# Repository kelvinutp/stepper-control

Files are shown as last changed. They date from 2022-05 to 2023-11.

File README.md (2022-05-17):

# stepper controls

This repository will contain the file for controlling stepper motors using a Raspberry pi GPIO and TB6560 drivers

|program|function|
|---|---|
|[clk_signal.py](https://github.com/kelvinutp/stepper-control/blob/main/clock_signal.py)|Generates a constant frequency clock signal (square wave)|
|[only_motors_control.py](https://github.com/kelvinutp/stepper-control/blob/main/only_motors_control.py)|Allows for controlling individual Enable (start/stop) and Direction (changes direction) pin on driver|
|[auto_moving.py](https://github.com/kelvinutp/stepper-control/blob/main/auto_moving.py)|Makes a motor moves repeteadly in prestablished timed sequences|
|[variador.py](https://github.com/kelvinutp/stepper-control/blob/main/variaddor.py)|enables the stepmotor for a soft start and a soft stop by gradually increasing and decreaseing th efrequency|
|[class.py](https://github.com/kelvinutp/stepper-control/blob/main/class.py)|A programmed class that provides all the functionalities for controlling a stepmotor|
|[Django files](https://github.com/kelvinutp/stepper-control/tree/main/django%20files)|a Django project created for providing a sort of UI capable of doing almost everything that is done by code|

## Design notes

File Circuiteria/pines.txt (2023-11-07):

signal=raspberry pin 
clk 18
D1 8
E1 10
D2 16
E3 18
D3 22
E3 24
D4 26
E4 32
D5 36
E5 38
-----
LIMIT SWITCH
L1 31
L2 33
L3 35
L4 37
L5 40

---
ENCODERS
ENC1A 3
ENC1B 5
ENC2A 7
ENC2B 11
ENC3A 13
ENC3B 15
ENC4A 19
ENC4B 21
ENC5A 23
ENC5B 29

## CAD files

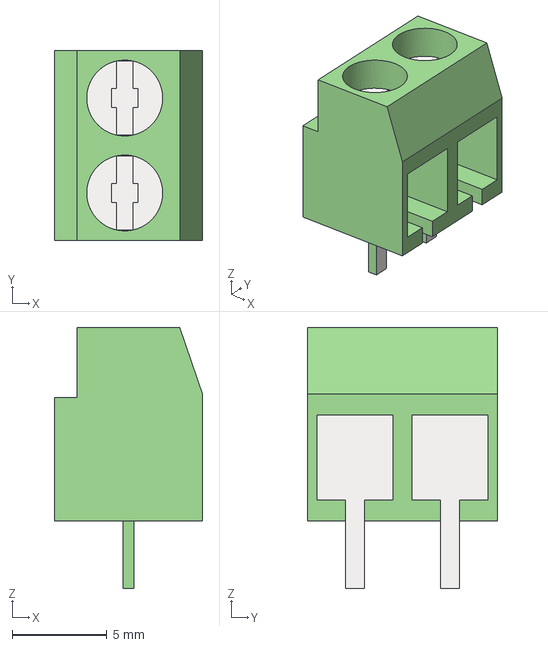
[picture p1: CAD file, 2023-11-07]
Circuiteria/modelos 3d de piezas/bornera 2.step
7.80 x 10.0 x 13.8 mm

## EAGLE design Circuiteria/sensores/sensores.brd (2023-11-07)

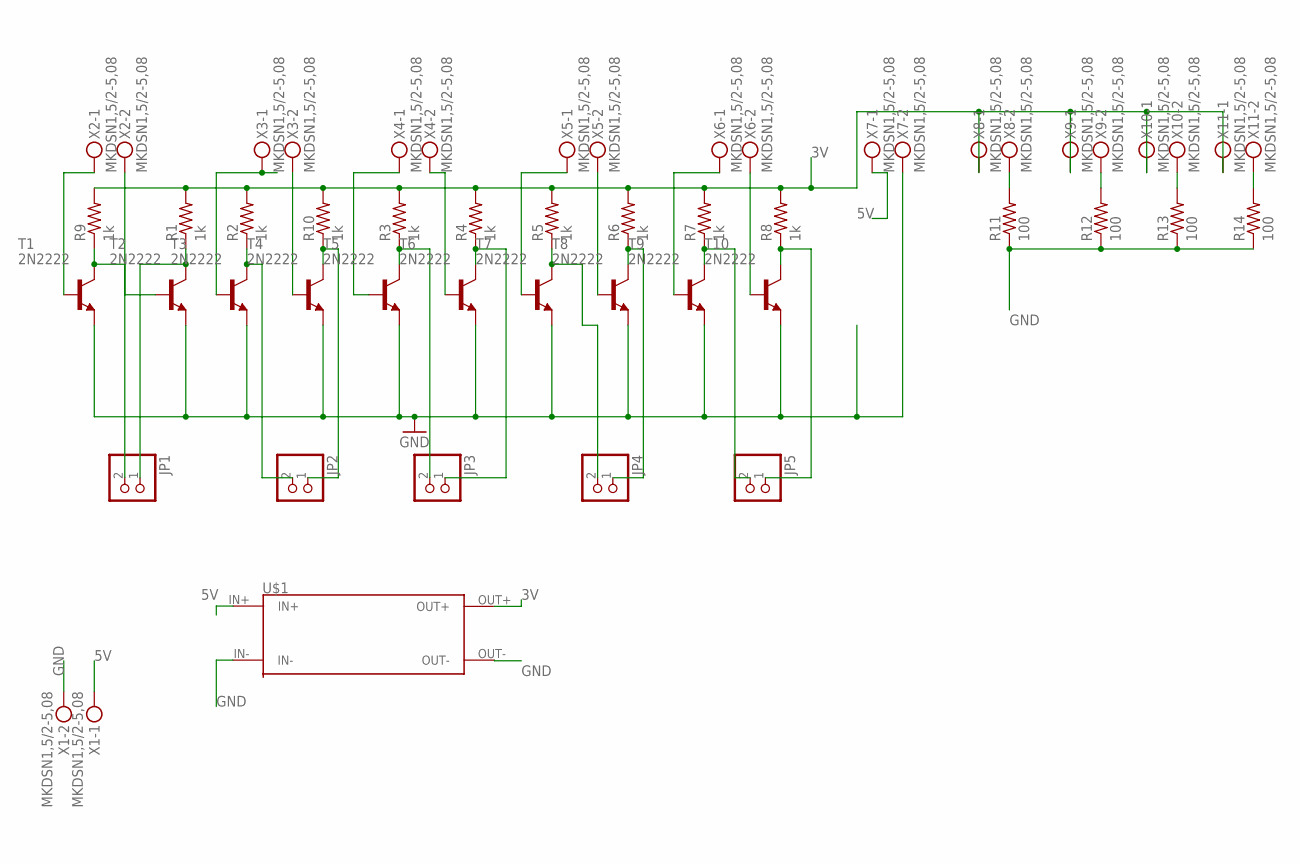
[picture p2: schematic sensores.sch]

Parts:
JP1, JP2, JP3, JP4, JP5: PINHD-1X2; 1X02
R1, R2, R3, R4, R5, R6, R7, R8, R9, R10: 1k; 0207/10
R11, R12, R13, R14: 100; 0207/10
T1, T2, T3, T4, T5, T6, T7, T8, T9, T10: 2N2222
U$1: LM2596
X1, X2, X3, X4, X5, X6, X7, X8, X9, X10, X11: MKDSN1,5/2-5,08

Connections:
3V: R1.2, R2.2, R3.2, R4.2, R5.2, R6.2, R7.2, R8.2, R9.2, R10.2, U$1.OUT+, X8.1, X9.1, X10.1, X11.1
5V: U$1.IN+, X1.1, X7.1
GND: R11.1, R12.1, R13.1, R14.1, T1.E, T2.E, T3.E, T4.E, T5.E, T6.E, T7.E, T8.E, T9.E, T10.E, U$1.IN-, U$1.OUT-, X1.2, X7.2
unnamed: T1.B, X2.1
unnamed: T4.B, X3.2
unnamed: T2.B, X2.2
unnamed: T3.B, X3.1
unnamed: T5.B, X4.1
unnamed: T6.B, X4.2
unnamed: T7.B, X5.1
unnamed: T8.B, X5.2
unnamed: T9.B, X6.1
unnamed: T10.B, X6.2
unnamed: JP3.1, R4.1, T6.C
unnamed: JP1.1, R1.1, T2.C
unnamed: JP2.2, R2.1, T3.C
unnamed: JP3.2, R3.1, T5.C
unnamed: JP4.2, R5.1, T7.C
unnamed: JP4.1, R6.1, T8.C
unnamed: JP5.2, R7.1, T9.C
unnamed: JP5.1, R8.1, T10.C
unnamed: JP1.2, R9.1, T1.C
unnamed: JP2.1, R10.1, T4.C
unnamed: R11.2, X8.2
unnamed: R12.2, X9.2
unnamed: R13.2, X10.2
unnamed: R14.2, X11.2

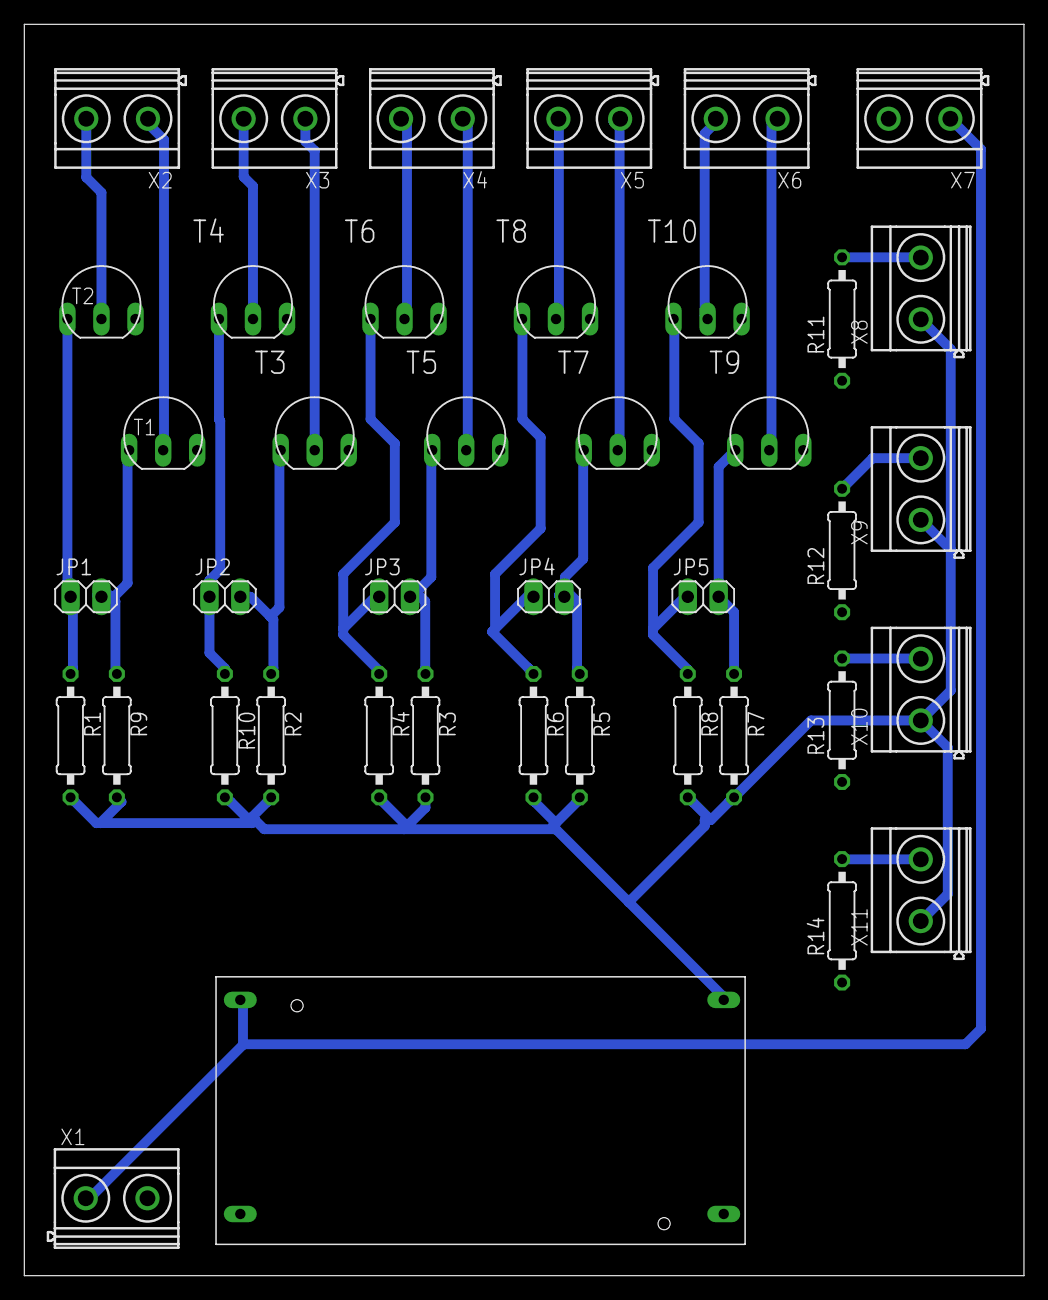
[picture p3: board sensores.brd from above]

Board: 2 copper layers, 82.3 x 103.0 mm, 41 parts (0 on the bottom side), 27 nets.

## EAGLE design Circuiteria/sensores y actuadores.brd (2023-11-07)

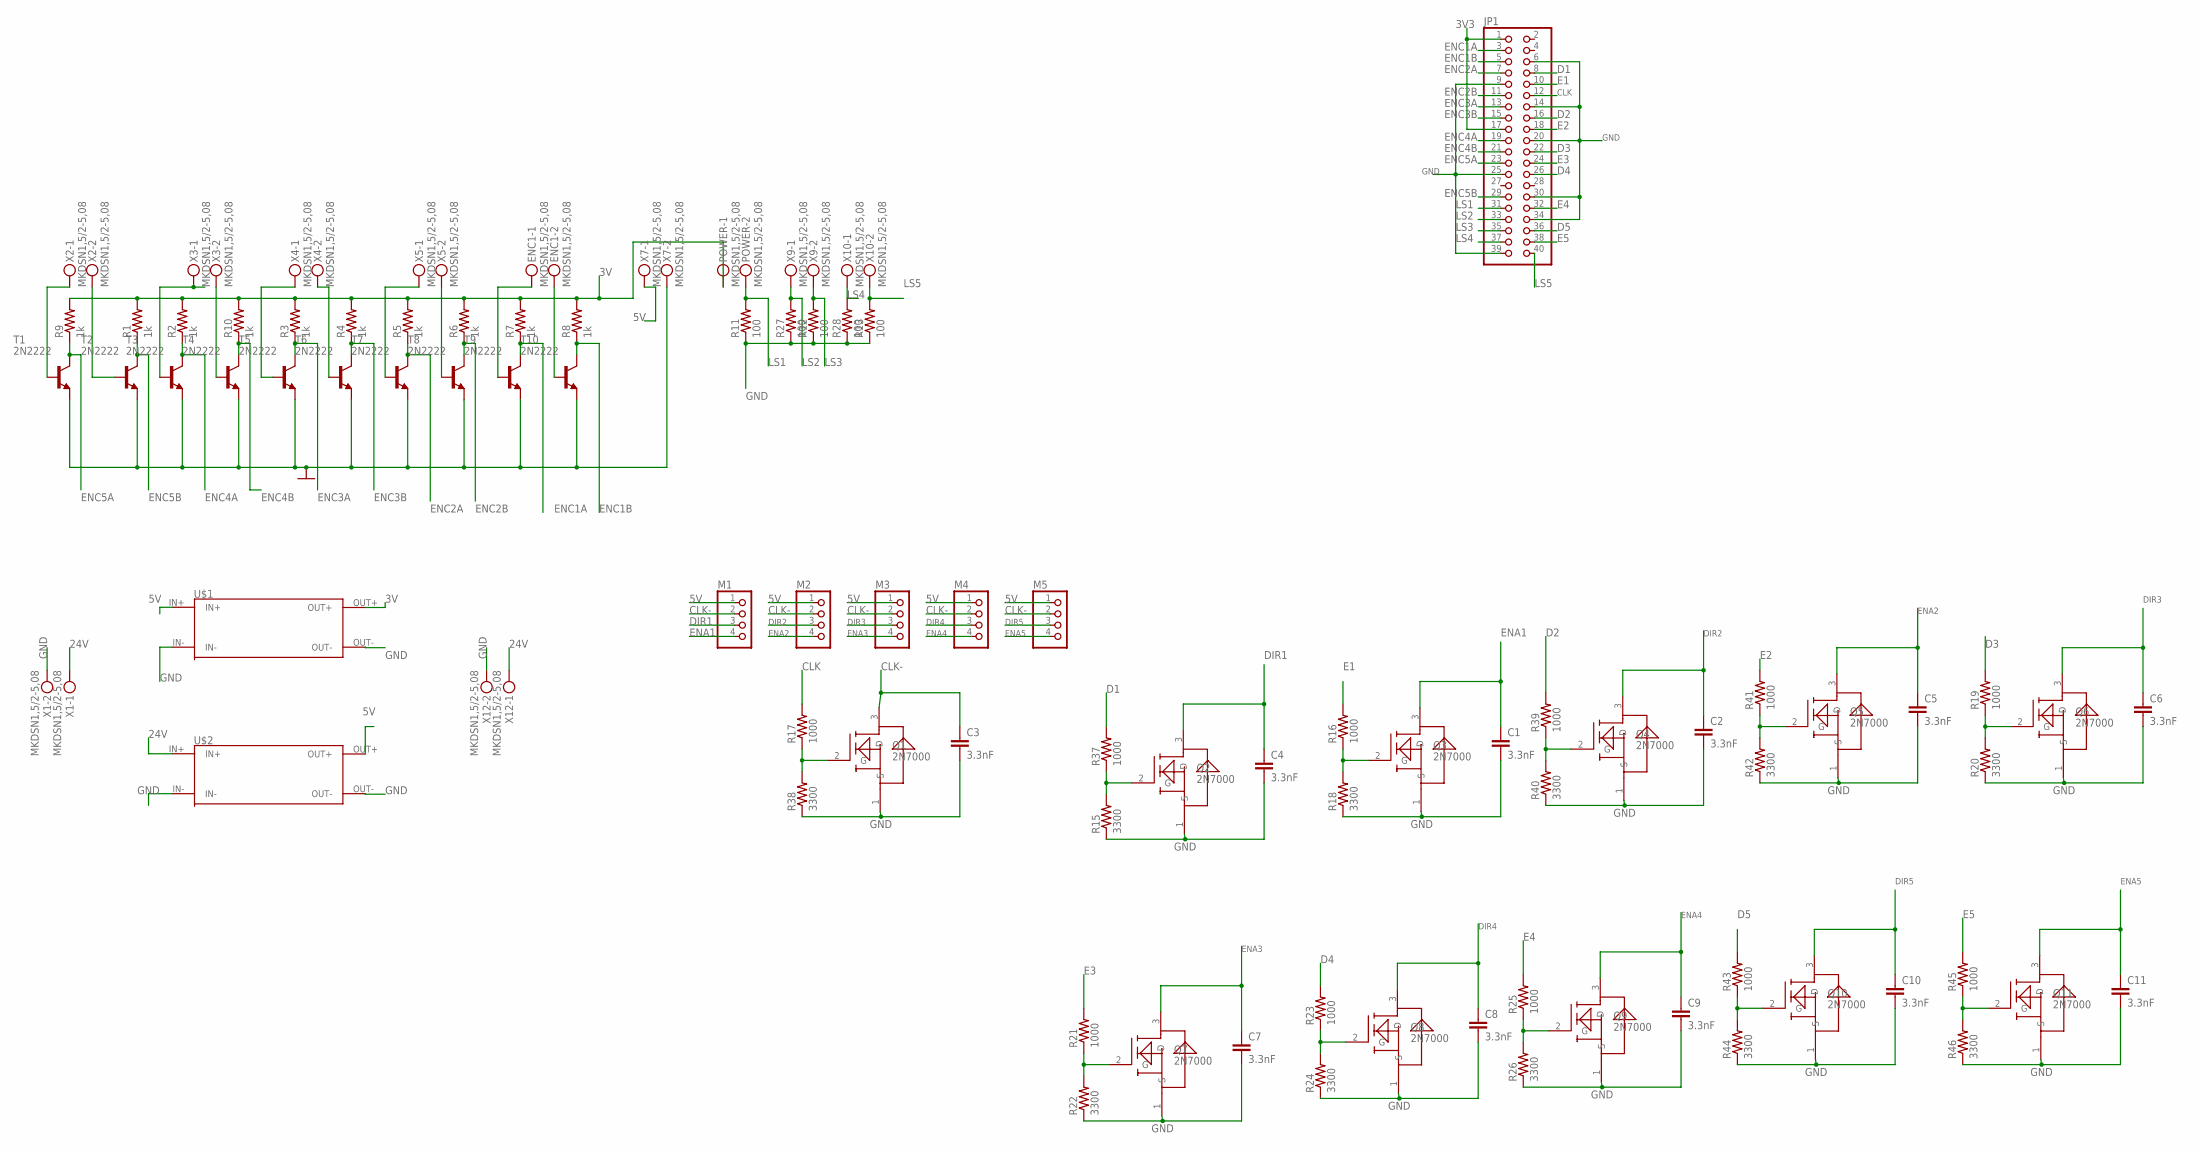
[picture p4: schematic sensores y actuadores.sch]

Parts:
C1, C2, C3, C4, C5, C6, C7, C8, C9, C10, C11: 3.3nF; C025-024X044
ENC1: MKDSN1,5/2-5,08
JP1: PINHD-2X20; 2X20
M1, M2, M3, M4, M5: PINHD-1X4; 1X04
POWER: MKDSN1,5/2-5,08
Q1, Q2, Q3, Q4, Q5, Q6, Q7, Q8, Q9, Q10, Q11: 2N7000
R1, R2, R3, R4, R5, R6, R7, R8, R9, R10: 1k; 0207/10
R11, R12, R13, R27, R28: 100; 0207/10
R15, R18, R20, R22, R24, R26, R38, R40, R42, R44, R46: 3300; 0207/10
R16, R17, R19, R21, R23, R25, R37, R39, R41, R43, R45: 1000; 0207/10
T1, T2, T3, T4, T5, T6, T7, T8, T9, T10: 2N2222
U$1, U$2: LM2596
X1, X2, X3, X4, X5, X7, X9, X10, X12: MKDSN1,5/2-5,08

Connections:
3V: POWER.1, R1.2, R2.2, R3.2, R4.2, R5.2, R6.2, R7.2, R8.2, R9.2, R10.2, U$1.OUT+
3V3: JP1.1, JP1.17
5V: M1.1, M2.1, M3.1, M4.1, M5.1, U$1.IN+, U$2.OUT+, X7.1
24V: U$2.IN+, X1.1, X12.1
CLK: JP1.12, R17.2
CLK-: C3.1, M1.2, M2.2, M3.2, M4.2, M5.2, Q1.3 (D)
D1: JP1.8, R37.2
D2: JP1.16, R39.2
D3: JP1.22, R19.2
D4: JP1.26, R23.2
D5: JP1.36, R43.2
DIR1: C4.1, M1.3, Q2.3 (D)
DIR2: C2.1, M2.3, Q4.3 (D)
DIR3: C6.1, M3.3, Q6.3 (D)
DIR4: C8.1, M4.3, Q8.3 (D)
DIR5: C10.1, M5.3, Q10.3 (D)
E1: JP1.10, R16.2
E2: JP1.18, R41.2
E3: JP1.24, R21.2
E4: JP1.32, R25.2
E5: JP1.38, R45.2
ENA1: C1.1, M1.4, Q3.3 (D)
ENA2: C5.1, M2.4, Q5.3 (D)
ENA3: C7.1, M3.4, Q7.3 (D)
ENA4: C9.1, M4.4, Q9.3 (D)
ENA5: C11.1, M5.4, Q11.3 (D)
ENC1A: JP1.3, R7.1, T9.C
ENC1B: JP1.5, R8.1, T10.C
ENC2A: JP1.7, R5.1, T7.C
ENC2B: JP1.11, R6.1, T8.C
ENC3A: JP1.13, R3.1, T5.C
ENC3B: JP1.15, R4.1, T6.C
ENC4A: JP1.19, R2.1, T3.C
ENC4B: JP1.21, R10.1, T4.C
ENC5A: JP1.23, R9.1, T1.C
ENC5B: JP1.29, R1.1, T2.C
GND: C1.2, C2.2, C3.2, C4.2, C5.2, C6.2, C7.2, C8.2, C9.2, C10.2, C11.2, JP1.6, JP1.9, JP1.14, JP1.20, JP1.25, JP1.30, JP1.34, JP1.39, Q1.1 (S), Q2.1 (S), Q3.1 (S), Q4.1 (S), Q5.1 (S), Q6.1 (S), Q7.1 (S), Q8.1 (S), Q9.1 (S), Q10.1 (S), Q11.1 (S), R11.1, R12.1, R13.1, R15.1, R18.1, R20.1, R22.1, R24.1, R26.1, R27.1, R28.1, R38.1, R40.1, R42.1, R44.1, R46.1, T1.E, T2.E, T3.E, T4.E, T5.E, T6.E, T7.E, T8.E, T9.E, T10.E, U$1.IN-, U$1.OUT-, U$2.IN-, U$2.OUT-, X1.2, X7.2, X12.2
LS1: JP1.31, POWER.2, R11.2
LS2: JP1.33, R27.2, X9.1
LS3: JP1.35, R12.2, X9.2
LS4: JP1.37, R28.2, X10.1
LS5: JP1.40, R13.2, X10.2
unnamed: T1.B, X2.1
unnamed: T4.B, X3.2
unnamed: T2.B, X2.2
unnamed: T3.B, X3.1
unnamed: T5.B, X4.1
unnamed: T6.B, X4.2
unnamed: T7.B, X5.1
unnamed: T8.B, X5.2
unnamed: ENC1.1, T9.B
unnamed: ENC1.2, T10.B
unnamed: Q1.2 (G), R17.1, R38.2
unnamed: Q2.2 (G), R15.2, R37.1
unnamed: Q3.2 (G), R16.1, R18.2
unnamed: Q4.2 (G), R39.1, R40.2
unnamed: Q5.2 (G), R41.1, R42.2
unnamed: Q6.2 (G), R19.1, R20.2
unnamed: Q7.2 (G), R21.1, R22.2
unnamed: Q8.2 (G), R23.1, R24.2
unnamed: Q9.2 (G), R25.1, R26.2
unnamed: Q10.2 (G), R43.1, R44.2
unnamed: Q11.2 (G), R45.1, R46.2

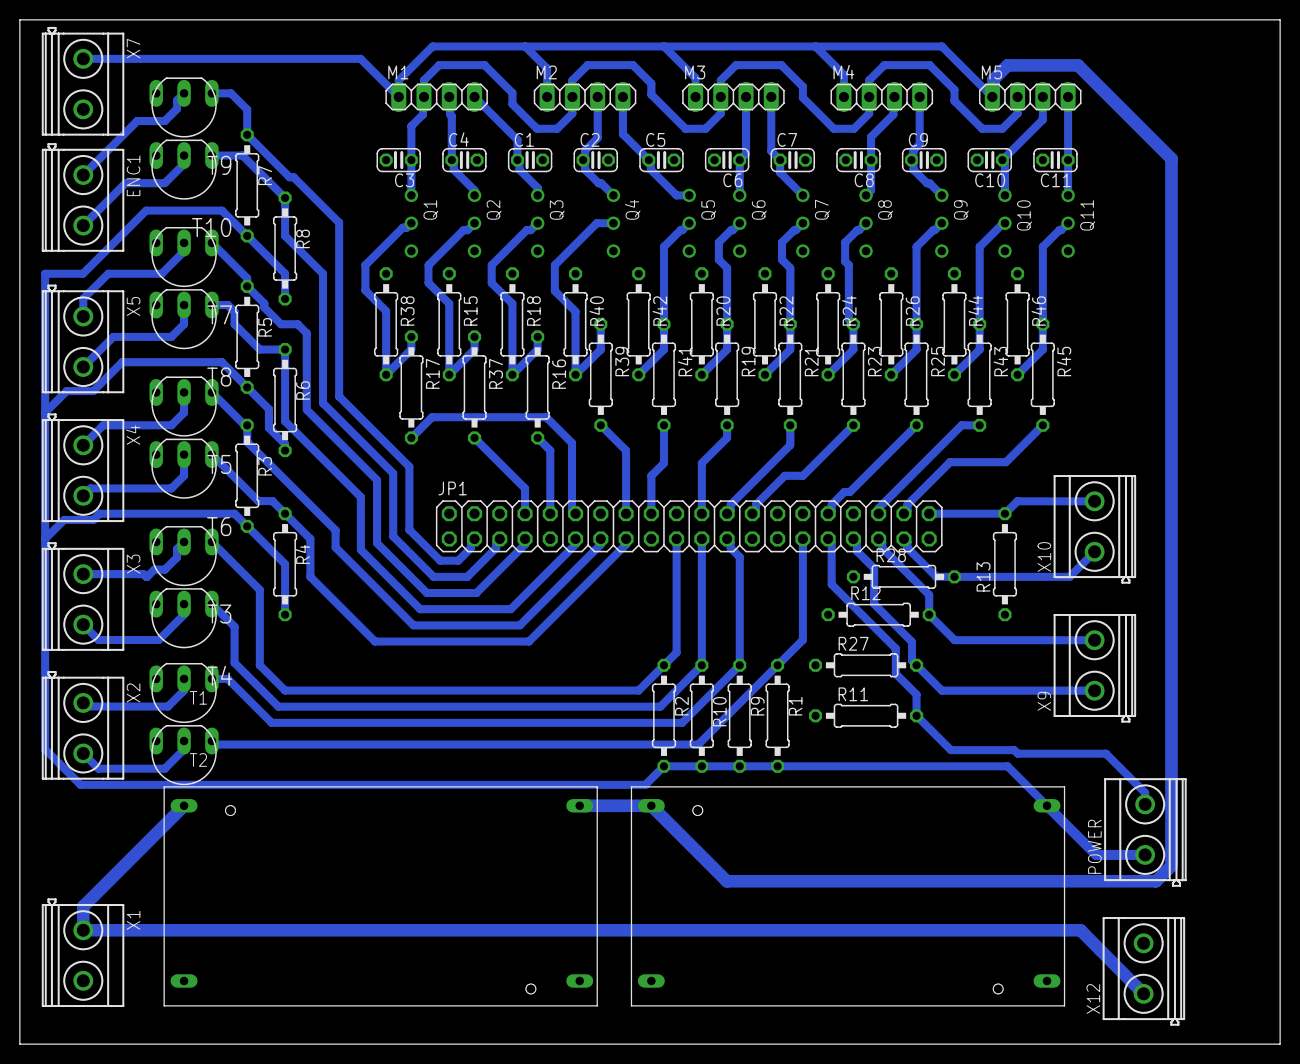
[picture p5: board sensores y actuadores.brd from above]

Board: 2 copper layers, 126.7 x 103.0 mm, 88 parts (0 on the bottom side), 63 nets.

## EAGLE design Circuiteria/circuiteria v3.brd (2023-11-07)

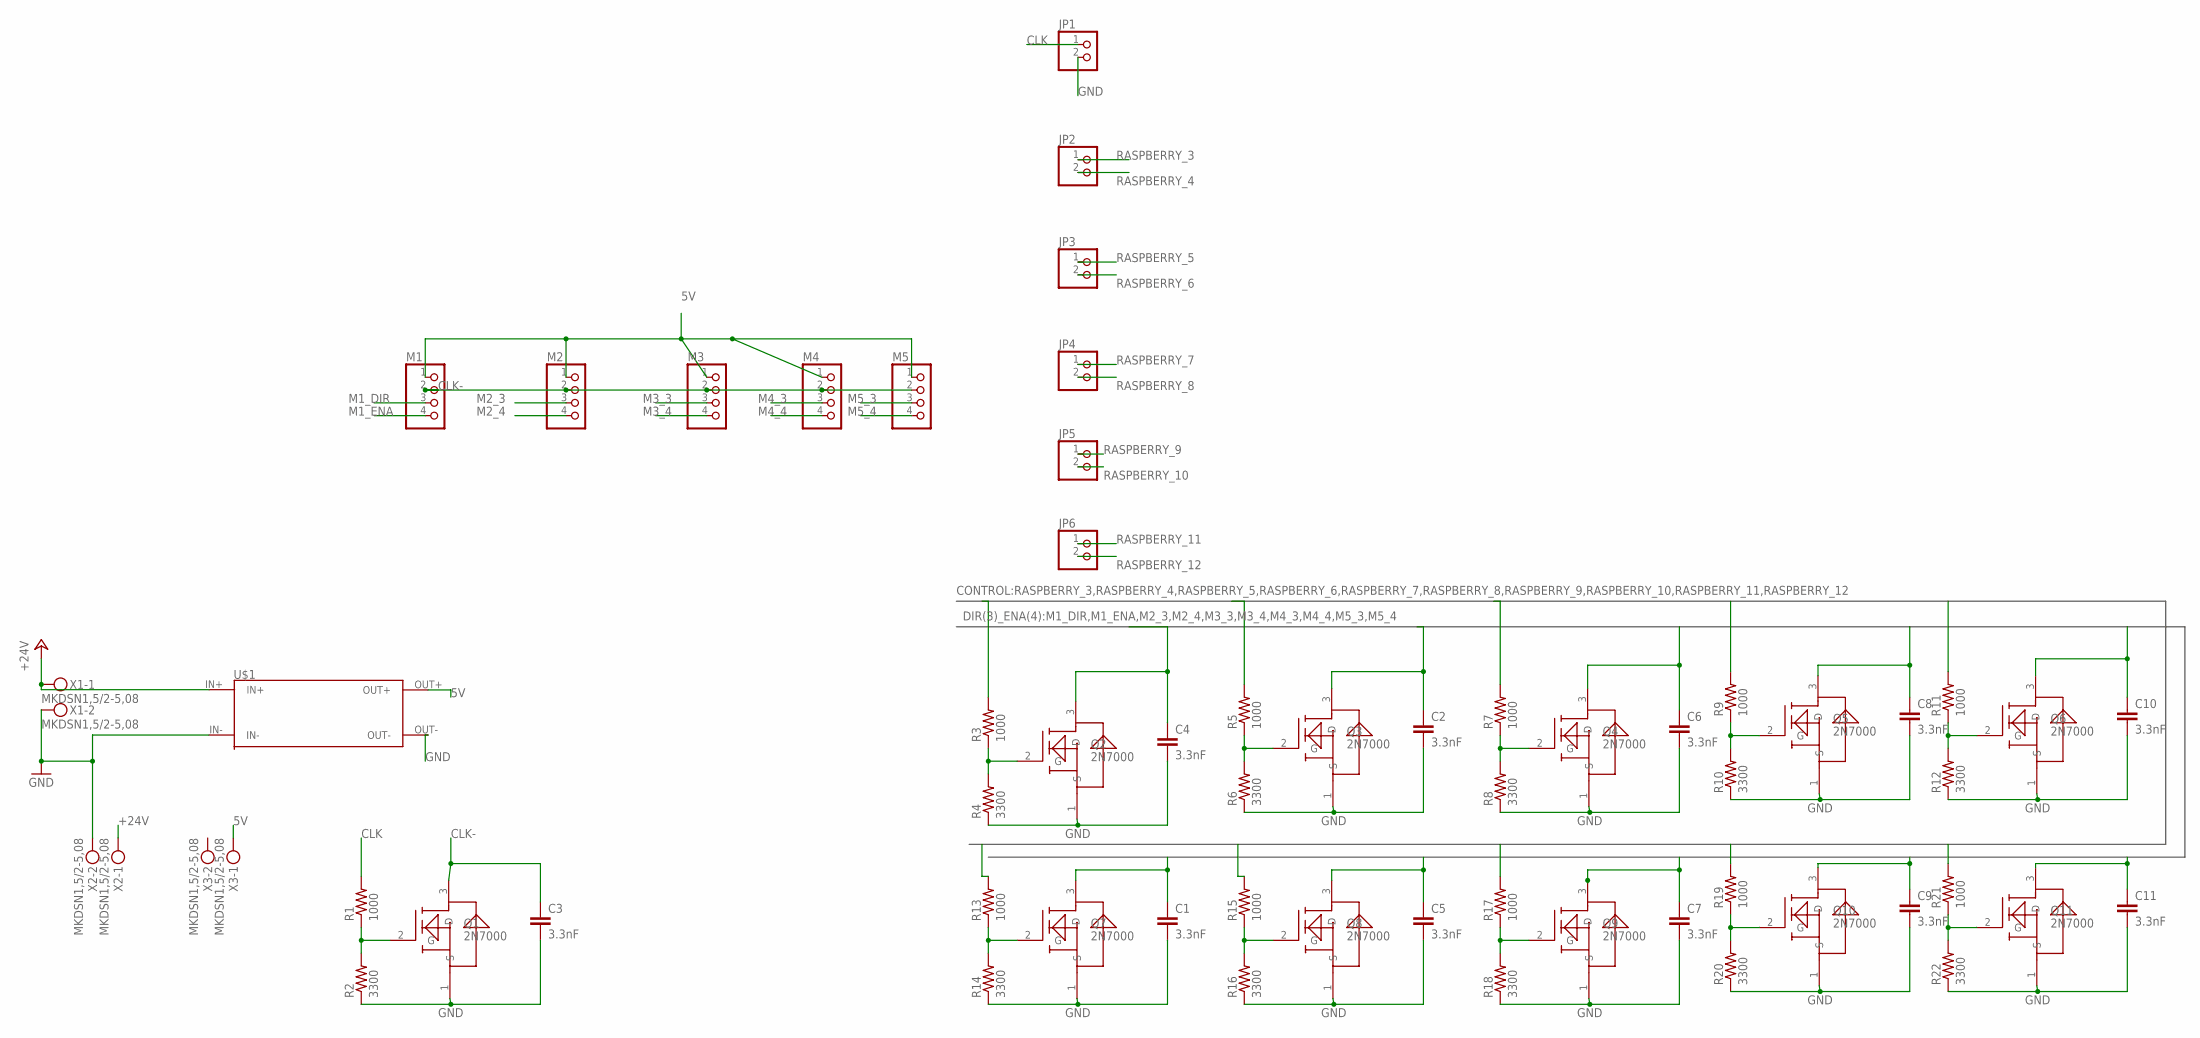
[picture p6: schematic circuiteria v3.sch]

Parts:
C1, C2, C3, C4, C5, C6, C7, C8, C9, C10, C11: 3.3nF; C025-024X044
JP1, JP2, JP3, JP4, JP5, JP6: PINHD-1X2; 1X02
M1, M2, M3, M4, M5: PINHD-1X4; 1X04
Q1, Q2, Q3, Q4, Q5, Q6, Q7, Q8, Q9, Q10, Q11: 2N7000
R1, R3, R5, R7, R9, R11, R13, R15, R17, R19, R21: 1000; 0411/15
R2, R4, R6, R8, R10, R12, R14, R16, R18, R20, R22: 3300; 0411/15
U$1: LM2596
X1, X2, X3: MKDSN1,5/2-5,08

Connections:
5V: M1.1, M2.1, M3.1, M4.1, M5.1, U$1.OUT+, X3.1
+24V: U$1.IN+, X1.1, X2.1
CLK: JP1.1, R1.2
CLK-: C3.1, M1.2, M2.2, M3.2, M4.2, M5.2, Q1.3 (D)
GND: C1.2, C2.2, C3.2, C4.2, C5.2, C6.2, C7.2, C8.2, C9.2, C10.2, C11.2, JP1.2, Q1.1 (S), Q2.1 (S), Q3.1 (S), Q4.1 (S), Q5.1 (S), Q6.1 (S), Q7.1 (S), Q8.1 (S), Q9.1 (S), Q10.1 (S), Q11.1 (S), R2.1, R4.1, R6.1, R8.1, R10.1, R12.1, R14.1, R16.1, R18.1, R20.1, R22.1, U$1.IN-, U$1.OUT-, X1.2, X2.2
M1_DIR: C4.1, M1.3, Q2.3 (D)
M1_ENA: C2.1, M1.4, Q3.3 (D)
M2_3: C6.1, M2.3, Q4.3 (D)
M2_4: C8.1, M2.4, Q5.3 (D)
M3_3: C10.1, M3.3, Q6.3 (D)
M3_4: C1.1, M3.4, Q7.3 (D)
M4_3: C5.1, M4.3, Q8.3 (D)
M4_4: C7.1, M4.4, Q9.3 (D)
M5_3: C9.1, M5.3, Q10.3 (D)
M5_4: C11.1, M5.4, Q11.3 (D)
unnamed: Q1.2 (G), R1.1, R2.2
unnamed: Q2.2 (G), R3.1, R4.2
unnamed: Q3.2 (G), R5.1, R6.2
unnamed: Q4.2 (G), R7.1, R8.2
unnamed: Q5.2 (G), R9.1, R10.2
unnamed: Q6.2 (G), R11.1, R12.2
unnamed: Q7.2 (G), R13.1, R14.2
unnamed: Q8.2 (G), R15.1, R16.2
unnamed: Q9.2 (G), R17.1, R18.2
unnamed: Q10.2 (G), R19.1, R20.2
unnamed: Q11.2 (G), R21.1, R22.2
RASPBERRY_3: JP2.1, R3.2
RASPBERRY_4: JP2.2, R5.2
RASPBERRY_5: JP3.1, R7.2
RASPBERRY_6: JP3.2, R9.2
RASPBERRY_7: JP4.1, R11.2
RASPBERRY_8: JP4.2, R13.2
RASPBERRY_9: JP5.1, R15.2
RASPBERRY_10: JP5.2, R17.2
RASPBERRY_11: JP6.1, R19.2
RASPBERRY_12: JP6.2, R21.2

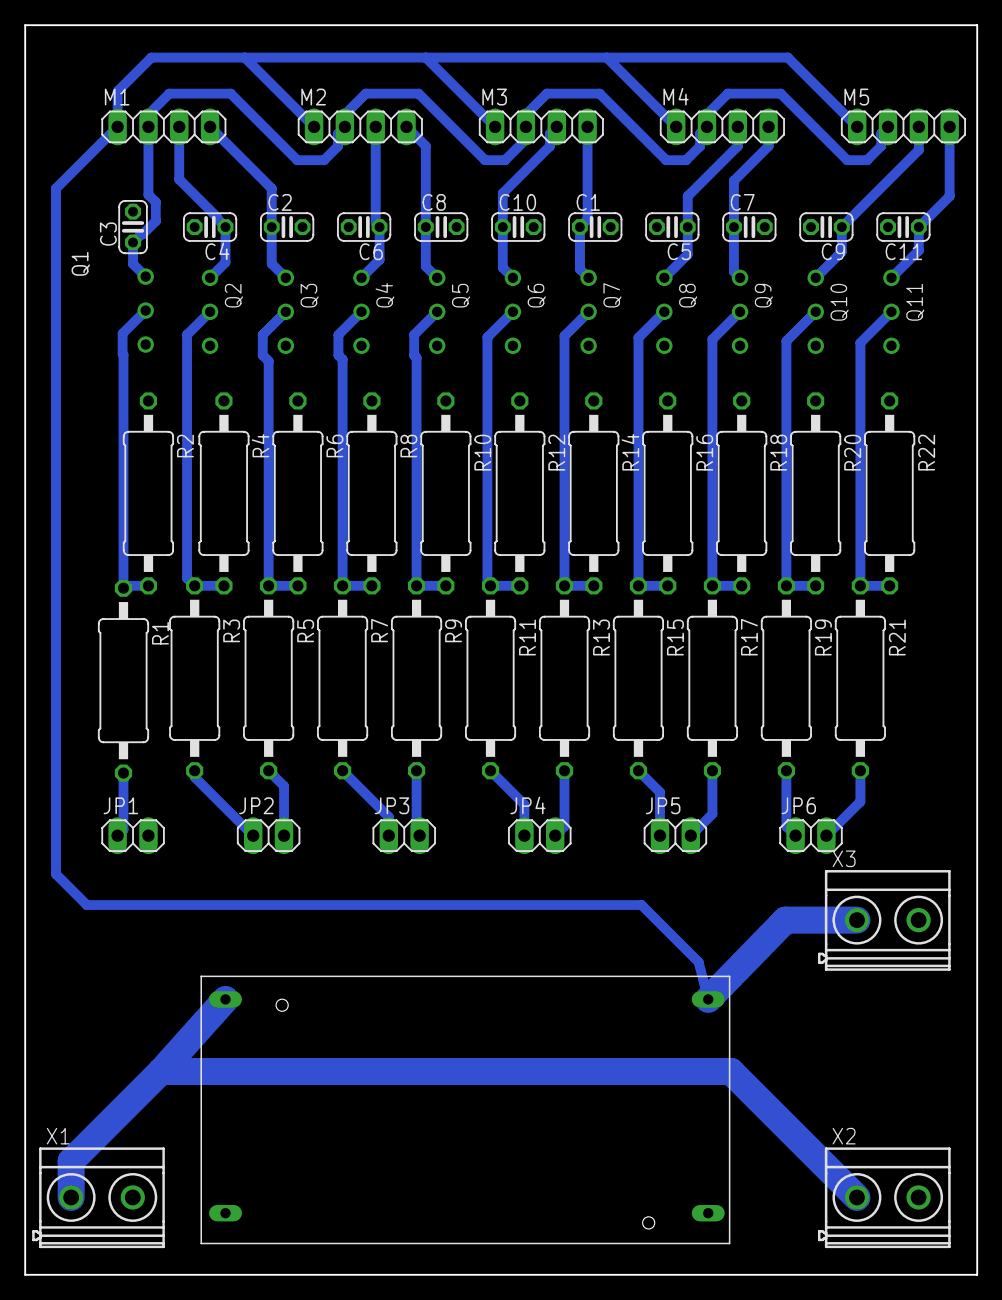
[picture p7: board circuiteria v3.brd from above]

Board: 2 copper layers, 78.5 x 103.0 mm, 59 parts (0 on the bottom side), 36 nets.

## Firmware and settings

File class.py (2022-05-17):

import pigpio
import time

pi=pigpio.pi()
clk=18
freq=1000

class gryphon:
    def __init__(self,dire,ena,enca,encb,rango,ls=[]):
        """
        dire=   GPIO direccion\n
        ena=    GPIO enable\n
        enca=   GPIO encoder A\n
        encb=   GPIO encoder B\n
        rango=  la totalidad de rango angular disponible\n
        ls    GPIO limit switches (maximo 2)\n
        """
        self.dire=dire
        self.ena=ena
        self.ls=ls
        self.enca=enca
        self.encb=encb
        self.estado={}
        self.rango=rango


        self.ls_anterior=0

        self.current_angle=360 #declaracion para que busque el 0
        self.total_angle=0
        self.factor=0 #factor de conversion 
        
        sali=[self.dire,self.ena]
        entr=[self.enca,self.encb]

        for a in sali:
            pi.set_mode(a,pigpio.OUTPUT)
            pi.write(a,True)
            self.estado[a]=True
        
        #limit switch configuration
        for a in self.ls[:2]:
            pi.set_mode(a,pigpio.INPUT)
            pi.callback(a,pigpio.PUD_DOWN)
            pi.callback(a,0,self.__limit)

        #encoders configuration
        for a in entr:
            pi.set_mode(a,pigpio.INPUT)
            pi.callback(a,pigpio.PUD_DOWN)
            pi.callback(a,0,self.__encoder)
        
        #begin clk signal
        pi.hardware_PWM(clk,freq,500000)
            
    def show_GPIO(self):
        """
        Muestra los pines GPIO y sus respectivas conexiones
        shows GPIO and their 
        """
        print("GPIO de direccion: ",self.dire)
        print("GPIO de enable:    ",self.ena)
        print("GPIO de encoder A: ",self.enca)
        print("GPIO de encoder B: ",self.encb)
        if len(self.ls)!=0:
            for a in self.ls:
                print('GPIO de limit switch:', a)
        print()
    
    def show_state(self):
        """
        Muestra el estado (True(1)/False(0)) de los GPIO
        """
        for a,b in self.estado.items():
            print("GPIO: {:>2}, Estado: {:<5}".format(a,b))
        print()
    
    def change(self,control,state):
        """
        control ("dir"/"ena")
        state(True/False)
        """
        if control.lower()=='dir':
            pin=self.dire
        elif control.lower()=='ena':
            pin=self.ena
        pi.write(pin,state)
        self.estado[pin]=state
        return
    
    def __limit(self,p,e,t):

        if self.ls_anterior!=p:
            if self.estado[self.dire]:
                self.current_angle=0
            else:
                self.total_angle=self.current_angle
            #cambia la direccion
            self.change('dir',not(self.estado[self.dire]))

            self.ls_anterior=p
        
        #detiene el enable
        self.change('ena',True)
        pi.write(self.ena,True)
        return
    
    def __encoder(self,p,e,t):
        # print(p)
        # if self.enca and not(self.encb):
        if self.encb and self.estado[self.dire]:
            self.current_angle-=1
        else:
            self.current_angle+=1

        return

    def calibracion(self):
        
        if len(self.ls)<=1:
            print("no se puede realizar un correcto proceso de calibracion, por solo tener 1 interruptor limite (limit switch)")
        else:
            self.show_state()

            print("proceso de calibracion, buscando angulo 0 (inicio)")
            while self.current_angle!=0:
                self.change('ena',False)
                # print('Grados actuales: ',self.current_angle)
            print(time.time())
            
            self.show_state()
            print('cambio de direccion, buscando maximo angulo (fin)')
            while self.total_angle==0:
                self.change('ena',False)
                # print('Grados actuales: ',self.current_angle)
            
            self.show_state()
            print('Proceso de calibracion finalizado')
            print(time.time())

            print('Total de pulsos: ',self.total_angle)
            self.factor=self.total_angle/self.rango
            print('Factor de conversion: ',self.factor)
            
            #finaliza en "medio" de recorrido
            while self.current_angle>=(self.total_angle*0.5):
                # print('Grados actuales: ',self.current_angle)
                self.change('ena',False)
            
            print('Ticks actuales: ',self.current_angle)
            print('Grados actuales: ',self.current_angle/self.factor)

            self.change('ena',True)
            print()

    def move(self,grados=0,w='cw',varia=False,step=0):
        '''
        grados=cantidad de grados a mover
        w= sentido de movimiento (CW) horario o (CCW)antihorario
        varia(True/False)= hacer movimiento con variacion de frecuencia
        step= cantidad de pasos a mover el brazo. 1.8grados/pasos para los motores actuales
        '''
        if step!=0 and grados==0:
            grados=step*1.8

        c=grados*self.factor

        if w.lower()=='ccw':
            print('sentido antihorario')
            self.change('dir',True)
            target=self.current_angle-c
            print('Actual: ',self.current_angle,'Destino: ',target)
            self.change('ena',False)
            while self.current_angle>=target:
                pass
        elif w.lower()=='cw':
            print('sentido horario')
            self.change('dir',False)
            target=self.current_angle+c        
            print('Actual: ',self.current_angle,'Destino: ',target)
            self.change('ena',False)
            while self.current_angle<=target:
                pass
        self.change('ena',True)
        print('Grados actuales: ',self.current_angle/self.factor)

    def variador (self, incremento=10,atraso=1):
        """
        incremento: delta frecuencia para incrementar/decrementar la frecuencia
        atraso (segundos): cuando tiempo demora en subir/bajar al siguiente escalon
        """
        print('se dara un incremento de: ', incremento)
        #incremento
        f_min=500
        f_max=1000
        for a in range(f_min,f_max+1,incremento):
            pi.hardware_PWM(clk,a,500000)
            time.sleep(atraso)
        
        #mantener frecuencia
        time.sleep(5)

        #decremento
        for a in range(f_max,f_min-1,-incremento):
            pi.hardware_PWM(clk,a,500000)
            time.sleep(atraso)
        
        return



if __name__=="__main__":
    try:
        m1=gryphon(14,15,2,3,270,[6,13])
        time.sleep(1)
        # m2=gryphon(23,24,4,17,165,[19,26])
        m1.show_GPIO()
        # m1.calibracion()
        # m2.calibracion()

        # time.sleep(10)
        # print('se moveran 30 grados sentido antihorario')
        # m1.move(30,'ccw')

        # time.sleep(2)
        # print('se moveran 90 grados sentido antihorario')
        # m1.move(90,'cw')
        time.sleep(2)
        m1.variador(25,2)


    except KeyboardInterrupt:
        m1.change('ena',True)
        print('\nPrograma interrumpido')

pi.hardware_PWM(clk,0,0)

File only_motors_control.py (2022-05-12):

import time
import pigpio
pi=pigpio.pi()

#GPIO pins
clk=18
#enable pins start/stop movement
ena=[15,24,8,12,20]
#dire pins change rotation  (clockwise/anticlockwise)
dire=[14,23,25,7,16]

#desired frequency
freq=1000

pin=ena+dire

state={}

#setting initial pin state=True
for a in pin:
    pi.set_mode(a,pigpio.OUTPUT)
    pi.write(a,True)
    state[a]=True

#starting clock signal
pi.hardware_PWM(clk,freq,500000)

c=pin[0]
e=0
while c in pin:
    #print pin and state
    for a in state:
        print("{:<2}: {}".format(a,state[a]))

    #changing desired pin state
    c=int(input("pin: "))
    try:
        d=not(state[c])
        state[c]=d
        pi.write(c,d)
        print()
    except KeyboardInterrupt:
        pi.hardware_PWM(clk,0,0)
    except:
        print("numero de pin incorrecto")

pi.hardware_PWM(clk,0,0)
print("Fin")
